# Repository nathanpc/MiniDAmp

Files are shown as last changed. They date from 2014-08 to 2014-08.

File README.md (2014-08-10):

# MiniDAmp

A low-distortion (<0.05% THD @ 1kHz) 44W (22W per channel) class AB power amplifier.

PCB Layout

## THD

This is the THD graph of the amplifier at full power into a 8 ohm load made using [plot_thd.py](https://gist.github.com/nathanpc/464b65f48d494179be13):

THD Graph

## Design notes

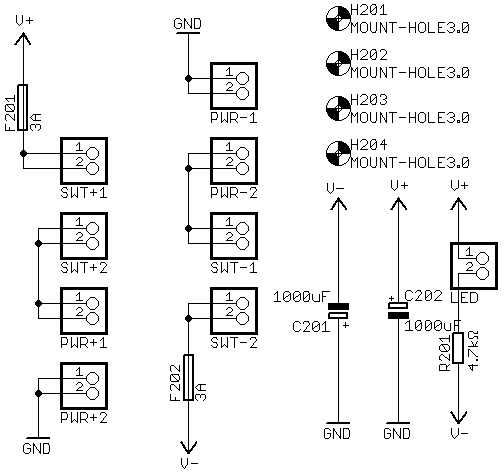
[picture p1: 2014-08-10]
images/Power Supply.png

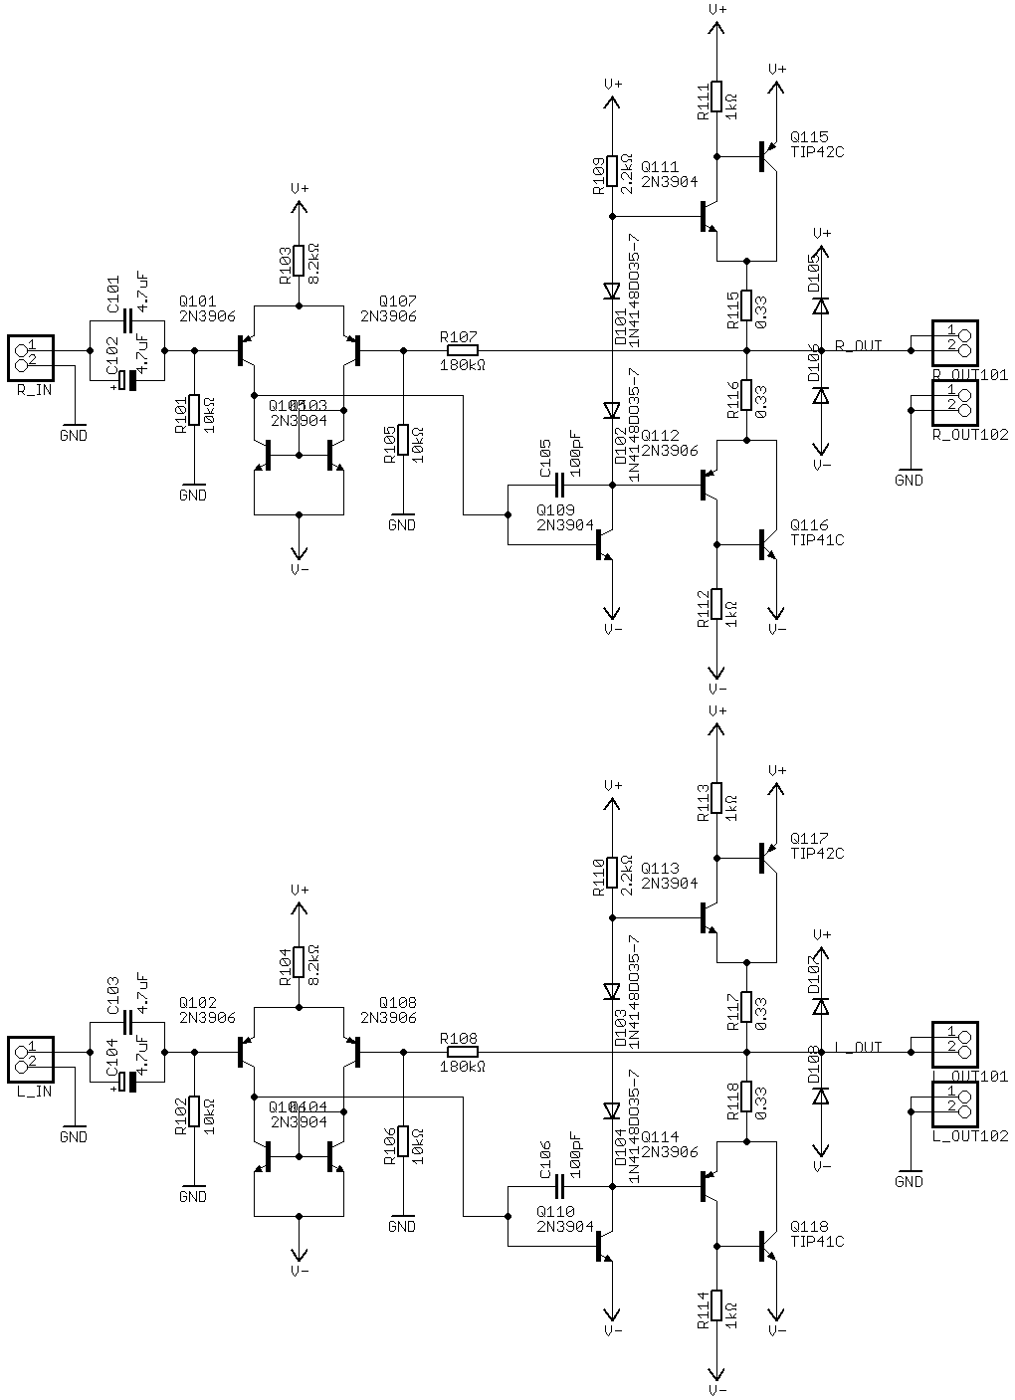
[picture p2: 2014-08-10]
images/Amplifier.png

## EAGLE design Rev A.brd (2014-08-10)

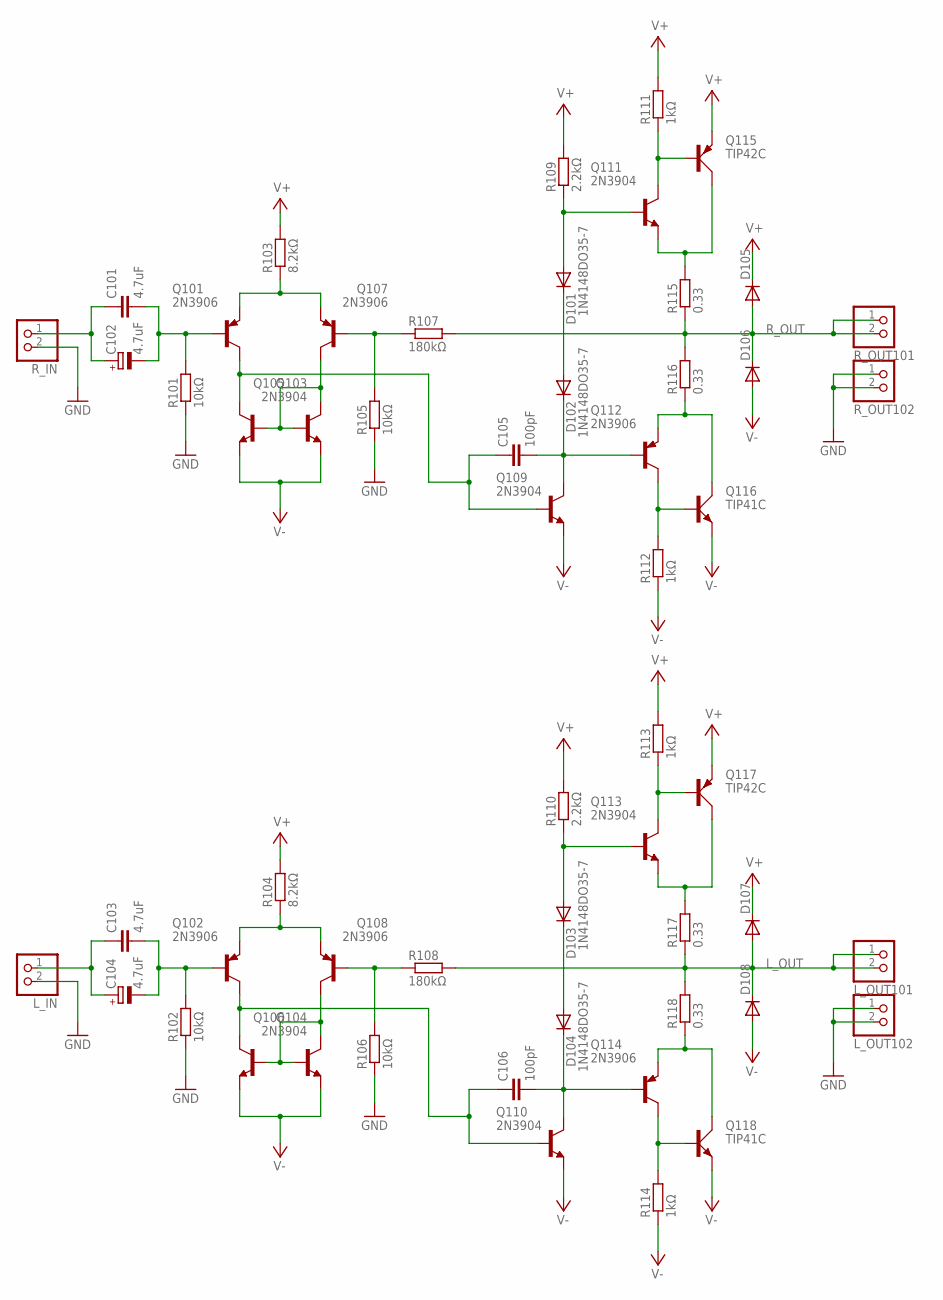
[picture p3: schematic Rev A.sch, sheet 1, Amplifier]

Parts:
C101, C103: 4.7uF; C225-113X268
C102, C104: 4.7uF; E2-5
C105, C106: 100pF; C050-050X075
D101, D102, D103, D104, D105, D106, D107, D108: 1N4148DO35-7; DO35-7
L_IN: JST_2PIN-THM; JST-PH-2-THM
L_OUT101, L_OUT102: JST_2PIN-THM; JST-PH-2-THM
Q101, Q102, Q107, Q108, Q112, Q114: 2N3906; TO92
Q103, Q104, Q105, Q106, Q109, Q110, Q111, Q113: 2N3904; TO92
Q115, Q117: TIP42C; TO220AV
Q116, Q118: TIP41C; TO220AV
R101, R102, R105, R106: 10kΩ; 0207/10
R103, R104: 8.2kΩ; 0207/10
R107, R108: 180kΩ; 0207/10
R109, R110: 2.2kΩ; 0207/10
R111, R112, R113, R114: 1kΩ; 0207/10
R115, R116, R117, R118: 0.33; 0414/15
R_IN: JST_2PIN-THM; JST-PH-2-THM
R_OUT101, R_OUT102: JST_2PIN-THM; JST-PH-2-THM

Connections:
GND: L_IN.2 (1), L_OUT102.1 (2), L_OUT102.2 (1), R101.1, R102.1, R105.1, R106.1, R_IN.2 (1), R_OUT102.1 (2), R_OUT102.2 (1); also elsewhere on the board
L_OUT: D107.A, D108.C, L_OUT101.1 (2), L_OUT101.2 (1), R108.2, R117.1, R118.2
unnamed: D101.A, Q111.2 (B), R109.1
unnamed: Q101.3 (E), Q107.3 (E), R103.1
unnamed: Q103.2 (B), Q105.1 (C), Q105.2 (B), Q107.1 (C)
unnamed: Q104.2 (B), Q106.1 (C), Q106.2 (B), Q108.1 (C)
unnamed: C101.2, C102.-, Q101.2 (B), R101.2
unnamed: C101.1, C102.+, R_IN.1 (2)
unnamed: C105.1, Q101.1 (C), Q103.1 (C), Q109.2 (B)
unnamed: D101.C, D102.A
unnamed: C103.2, C104.-, Q102.2 (B), R102.2
unnamed: Q111.1 (C), Q115.B, R111.1
unnamed: Q112.1 (C), Q116.B, R112.2
unnamed: Q112.3 (E), Q116.C, R116.1
unnamed: Q111.3 (E), Q115.C, R115.2
unnamed: C103.1, C104.+, L_IN.1 (2)
unnamed: C105.2, D102.C, Q109.1 (C), Q112.2 (B)
unnamed: Q107.2 (B), R105.2, R107.1
unnamed: Q102.3 (E), Q108.3 (E), R104.1
unnamed: C106.1, Q102.1 (C), Q104.1 (C), Q110.2 (B)
unnamed: D103.C, D104.A
unnamed: D103.A, Q113.2 (B), R110.1
unnamed: Q113.1 (C), Q117.B, R113.1
unnamed: Q113.3 (E), Q117.C, R117.2
unnamed: Q114.1 (C), Q118.B, R114.2
unnamed: Q114.3 (E), Q118.C, R118.1
unnamed: C106.2, D104.C, Q110.1 (C), Q114.2 (B)
unnamed: Q108.2 (B), R106.2, R108.1
R_OUT: D105.A, D106.C, R107.2, R115.1, R116.2, R_OUT101.1 (2), R_OUT101.2 (1)
V+: D105.C, D107.C, Q115.E, Q117.E, R103.2, R104.2, R109.2, R110.2, R111.2, R113.2; also elsewhere on the board
V-: D106.A, D108.A, Q103.3 (E), Q104.3 (E), Q105.3 (E), Q106.3 (E), Q109.3 (E), Q110.3 (E), Q116.E, Q118.E, R112.1, R114.1; also elsewhere on the board

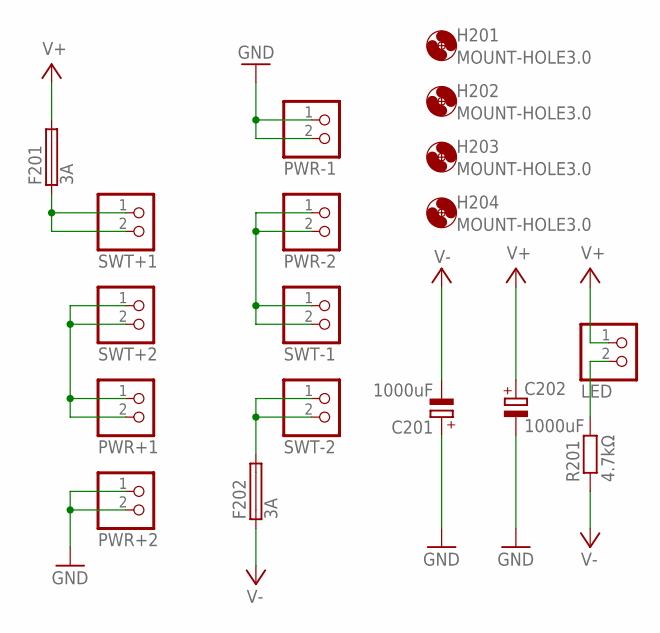
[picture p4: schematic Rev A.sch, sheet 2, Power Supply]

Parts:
C201, C202: 1000uF; E5-10,5
F201, F202: 3A; SH22,5
H201, H202, H203, H204: MOUNT-HOLE3.0; 3,0
LED: JST_2PIN-THM; JST-PH-2-THM
PWR+1, PWR+2: JST_2PIN-THM; JST-PH-2-THM
PWR-1, PWR-2: JST_2PIN-THM; JST-PH-2-THM
R201: 4.7kΩ; 0207/10
SWT+1, SWT+2: JST_2PIN-THM; JST-PH-2-THM
SWT-1, SWT-2: JST_2PIN-THM; JST-PH-2-THM

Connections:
GND: C201.+, C202.-, PWR+2.1 (2), PWR+2.2 (1), PWR-1.1 (2), PWR-1.2 (1); also elsewhere on the board
unnamed: LED.2 (1), R201.2
unnamed: PWR+1.1 (2), PWR+1.2 (1), SWT+2.1 (2), SWT+2.2 (1)
unnamed: PWR-2.1 (2), PWR-2.2 (1), SWT-1.1 (2), SWT-1.2 (1)
unnamed: F202.2, SWT-2.1 (2), SWT-2.2 (1)
unnamed: F201.1, SWT+1.1 (2), SWT+1.2 (1)
V+: C202.+, F201.2, LED.1 (2); also elsewhere on the board
V-: C201.-, F202.1, R201.1; also elsewhere on the board

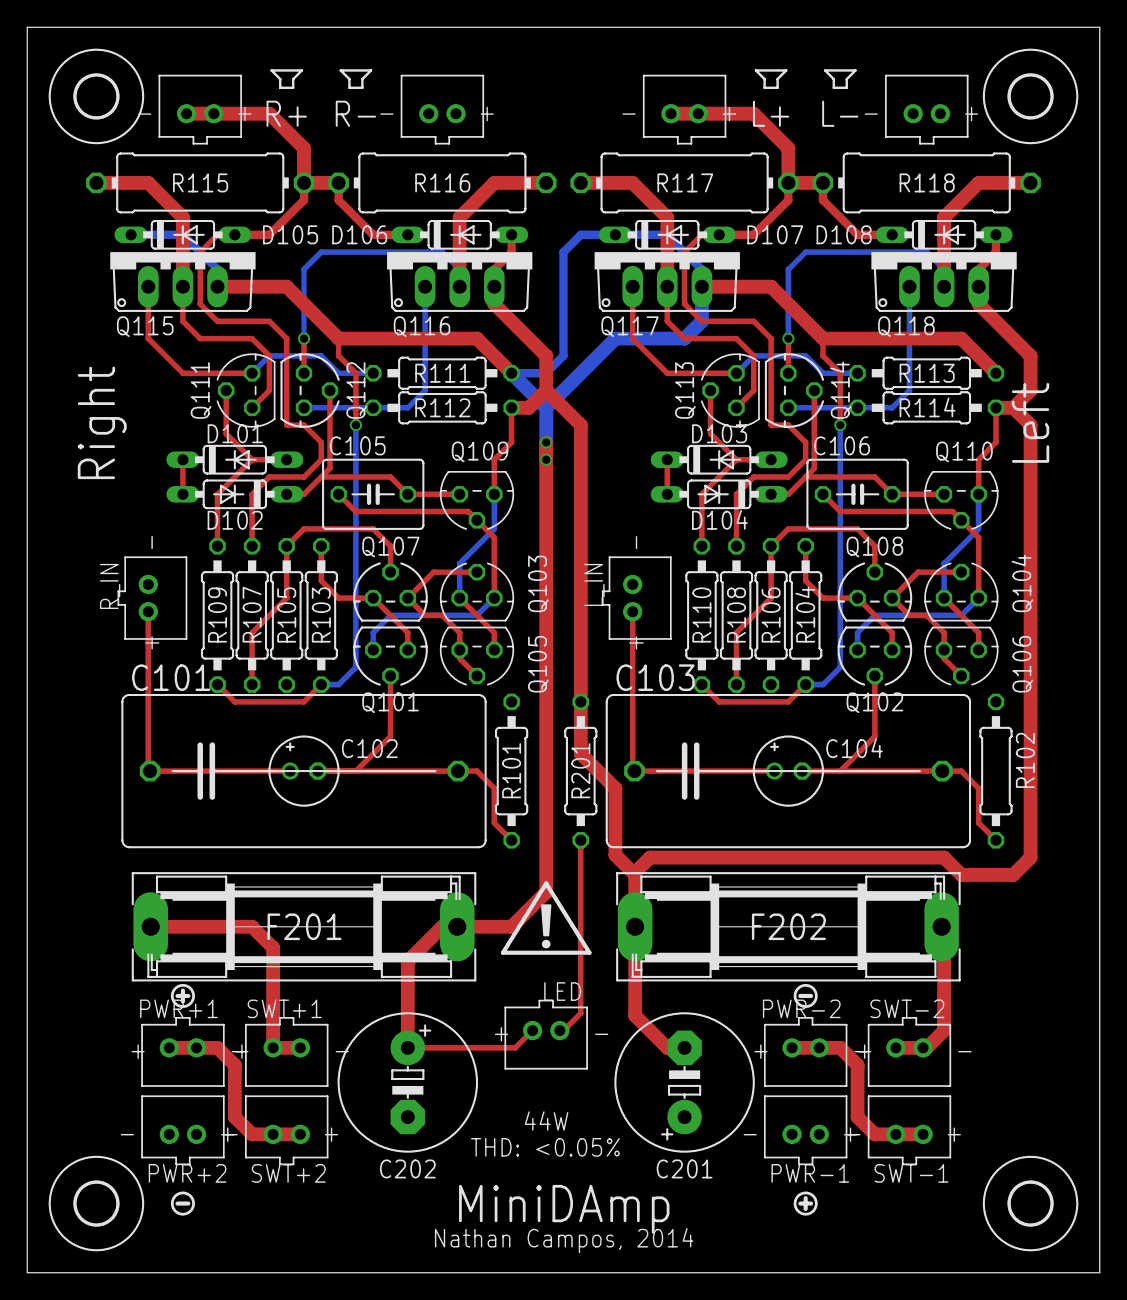
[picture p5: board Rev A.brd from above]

Board: 4 copper layers, 78.7 x 91.4 mm, 83 parts (0 on the bottom side), 36 nets.

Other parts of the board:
U$1: ICON_EXL-S
U$2, U$3: ICON_MINUS
U$4, U$5: ICON_PLUS
U$6, U$7, U$8, U$9: ICON_SPEAKER

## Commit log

2014-08-10 Finished the schematic
    [Rev A.sch]
2014-08-10 Added a title to each sheet
    [Rev A.sch]
2014-08-10 Fixed the reversed JST connectors
    [Rev A.sch]
2014-08-10 Made some changes to the connector arrangement in the power supply
    [Rev A.sch]
2014-08-10 Removed one LED
    [Rev A.sch]
2014-08-10 Made major changes to the schematic
    [Rev A.sch]
2014-08-10 Final changes
    [Rev A.sch]
2014-08-10 Finished the PCB layout
    [Rev A.brd]
2014-08-10 Exported the schematic and board layout
2014-08-10 Ready for production
    [Rev A.brd, Rev A.sch]

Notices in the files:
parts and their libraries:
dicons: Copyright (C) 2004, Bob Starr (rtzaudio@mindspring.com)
